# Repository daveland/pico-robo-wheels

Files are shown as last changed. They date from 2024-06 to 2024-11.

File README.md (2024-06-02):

# RoboWheels
This Project will control up to 4 DC servomotors on a robot platform.  The code runs on an RPI pico and uses PWM to perform Speed control of DC motors.  The Pico PIO blocks are used to monitor Quadrature  encoders for motor Speed and position sensing.  Closed loop Velocity control is performed on each motor with Pairs velocity locked to each other for electronic differential mode.  This make the platfor Track straight when 2 motors are determining direction.

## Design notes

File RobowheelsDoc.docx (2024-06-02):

5/2/2024

David Anderson

[company name]

RoboWheels

A Wheel control system for robots

RoboWheels -D.L.Anderson 6/2/24

A universal Wheel control Platform for Robots

Abstract: Robowheels attempts to be a universal control for 2 or 4 wheel DC servo motor robot platforms using microcontrollers. With H-bridge control and Quadrature encoder sensing, the Robowheels software will manage motor speed and position to send the platform in a given direction and speed, with measurable distance. It also supports acceleration control, faults, and wheel slip monitoring. Using Robowheels makes the low level control of the motors much simpler and generic.

When Designing wheeled robot platforms it is often a challenge to integrate the wheel control algorithms into the main system. Many systems are proprietary, and they place tight real-time constraints on the hardware needed to run them. By moving all lower level time critical motor control tasks to a single real-time OS running on a dedicated microcontroller, Robowheels eliminates much of the timing bottlenecks and design discussions. The motor platform is dealt with at a higher level with much fewer and slower timing constraints. Robowheels solves these issue by handling the fiddly details of motor control and gives a clean and deterministic interface for upper software layers to deal with. It still allows fine grained control of motor parameters but with a higher level of abstraction.

Realtime control requires a software system with dedicated processor resuorces organized to provide deterministic control of motor events. In the industry a RTOS software platform is usually used to provide layers of functionality that can meet the timing goals of the control system. The RTOS manages CPU time and events to insure that all tasks are performed at the exact time required by the control algorithm, Delays are managed by a priority system and pool of tasks that address the control algorithm. Interupts are used where appropriate to handle fast events that must be handled immediately. The RTOS and the application work together to meet all the control challengs and get the work done on time.

Key sections are shown below: PWM/Dir control, H-Bridge ,DC servo-Motor, Quadrature encoder, Geartrain and Wheel. The configuration of these objects can be changed to suit the application. Allowing different gear trains or motors to be tested with minimal code re-write.

Wheel

PWM

GearTrain

Quad Encoder

DC Servo motor

H-Bridge

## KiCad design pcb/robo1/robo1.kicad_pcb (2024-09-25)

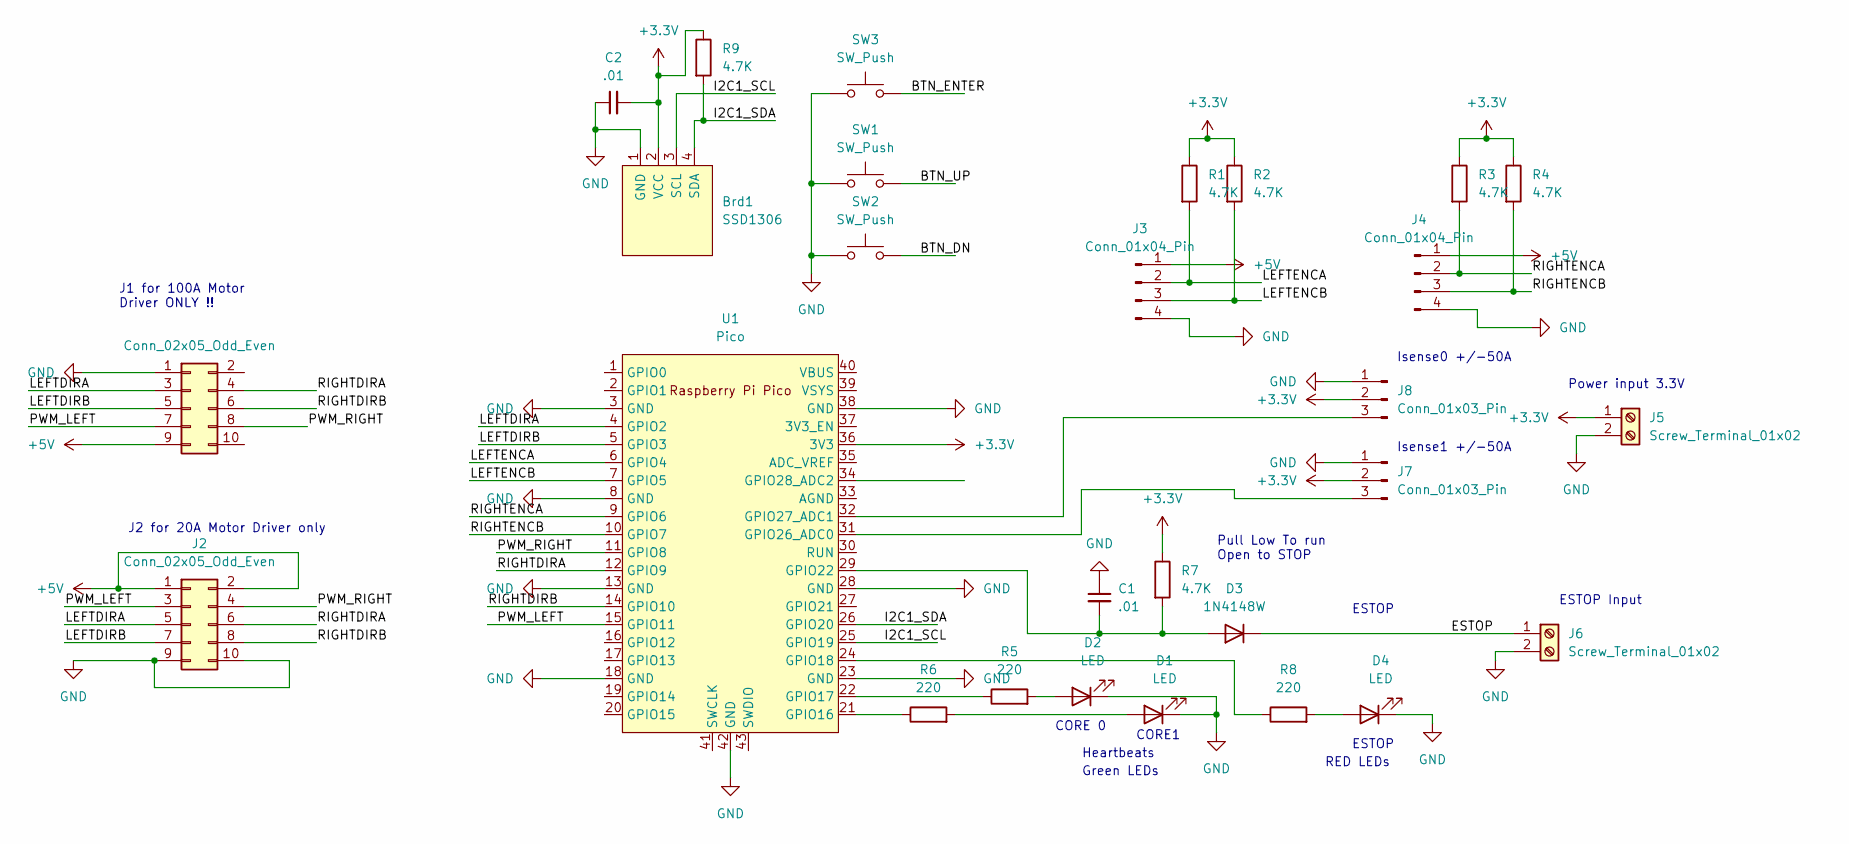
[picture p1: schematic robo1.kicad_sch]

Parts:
Brd1: SSD1306; 128x64OLED
C1, C2: .01; C_0603_1608Metric_Pad1.08x0.95mm_HandSolder
D1, D2, D4: LED; LED_1206_3216Metric_Pad1.42x1.75mm_HandSolder
D3: 1N4148W; D_SOD-123
J1, J2: Conn_02x05_Odd_Even; PinHeader_2x05_P2.54mm_Vertical
J3, J4: Conn_01x04_Pin; PinHeader_1x04_P2.54mm_Vertical
J5, J6: Screw_Terminal_01x02; TerminalBlock_bornier-2_P5.08mm
J7, J8: Conn_01x03_Pin; PinHeader_1x03_P2.54mm_Vertical
R1, R2, R3, R4, R7, R9: 4.7K; R_0201_0603Metric_Pad0.64x0.40mm_HandSolder
R5, R6, R8: 220; R_0201_0603Metric_Pad0.64x0.40mm_HandSolder
SW1, SW2, SW3: SW_Push; SW_PUSH_6mm
U1: Pico; RPi_Pico_SMD_TH

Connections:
+3.3V: Brd1.2 (VCC), C2.2, J5.1, J7.2, J8.2, R1.1, R2.1, R3.1, R4.1, R7.1, R9.1, U1.36 (3V3)
+5V: J1.9, J2.1, J2.2, J3.1, J4.1
/BTN_DN: SW2.2
/BTN_ENTER: SW3.2
/BTN_UP: SW1.2
/ESTOP: D3.1 (K), J6.1
/I2C1_SCL: Brd1.3 (SCL), U1.25 (GPIO19)
/I2C1_SDA: Brd1.4 (SDA), R9.2, U1.26 (GPIO20)
/LEFTDIRA: J1.3, J2.5, U1.4 (GPIO2)
/LEFTDIRB: J1.5, J2.7, U1.5 (GPIO3)
/LEFTENCA: J3.2, R1.2, U1.6 (GPIO4)
/LEFTENCB: J3.3, R2.2, U1.7 (GPIO5)
/PWM_LEFT: J1.7, J2.3, U1.15 (GPIO11)
/PWM_RIGHT: J1.8, J2.4, U1.11 (GPIO8)
/RIGHTDIRA: J1.4, J2.6, U1.12 (GPIO9)
/RIGHTDIRB: J1.6, J2.8, U1.14 (GPIO10)
/RIGHTENCA: J4.2, R3.2, U1.9 (GPIO6)
/RIGHTENCB: J4.3, R4.2, U1.10 (GPIO7)
GND: Brd1.1 (GND), C1.1, C2.1, D1.1 (K), D2.1 (K), D4.1 (K), J1.1, J2.9, J2.10, J3.4, J4.4, J5.2, J6.2, J7.1, J8.1, SW1.1, SW2.1, SW3.1, U1.3 (GND), U1.8 (GND), U1.13 (GND), U1.18 (GND), U1.23 (GND), U1.28 (GND), U1.38 (GND), U1.42 (GND)
unnamed: D1.2 (A), R6.2
unnamed: D2.2 (A), R5.2
unnamed: C1.2, D3.2 (A), R7.2, U1.29 (GPIO22)
unnamed: D4.2 (A), R8.2
unnamed: J7.3, U1.31 (GPIO26_ADC0)
unnamed: J8.3, U1.32 (GPIO27_ADC1)
unnamed: R6.1, U1.21 (GPIO16)
unnamed: R5.1, U1.22 (GPIO17)
unnamed: R8.1, U1.24 (GPIO18)

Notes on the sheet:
ESTOP Input
J2 for 20A Motor Driver only
ESTOP
Isense0 +/-50A
Isense1 +/-50A
Heartbeats
Pull Low To run Open to STOP
Green LEDs
Power input 3.3V
J1 for 100A Motor Driver ONLY !!
CORE1
CORE 0
RED LEDs

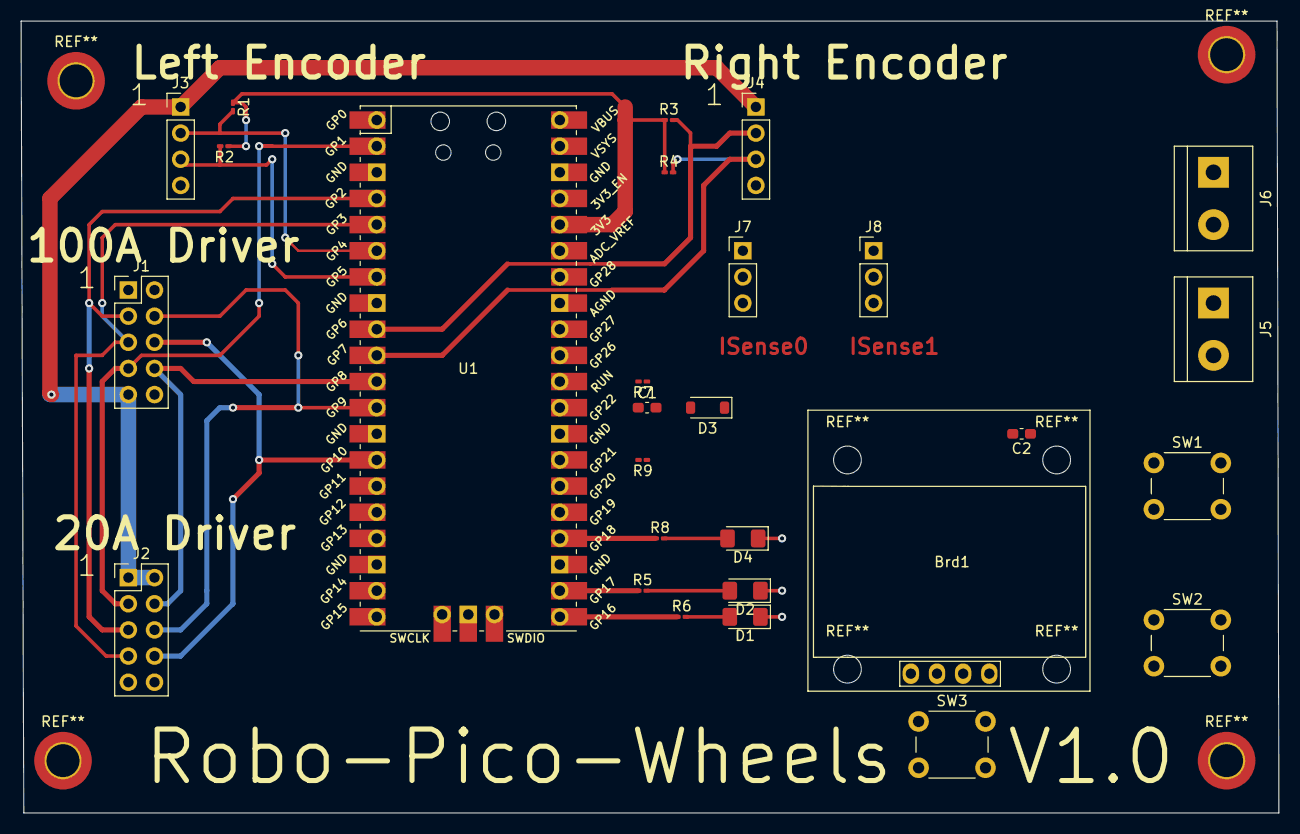
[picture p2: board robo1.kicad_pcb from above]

Board: 2 copper layers, 122.2 x 76.9 mm, 28 parts (0 on the bottom side), 25 nets.

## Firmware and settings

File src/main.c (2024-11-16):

/** pico-robo-wheels july 2024 -- "The beginning of Davenet" and the robot appocolypse
 * Copyright (C) 2024 {David L. Anderson} - All Rights Reserved
 * 
 * This source code is protected under international copyright law.  All rights
 * reserved and protected by the copyright holders.
 * This file is confidential and only available to authorized individuals with the
 * permission of the copyright holders.  If you encounter this file and do not have
 * permission, please contact the copyright holders and delete this file.
 */



#include "FreeRTOS.h"
#include "task.h"
#include "queue.h"
#include <stdio.h>
#include <stdlib.h>
#include "pico/stdlib.h"
#include "pico/unique_id.h"  //eeprom unique_id
#include "string.h"
#include "pico-robo-wheels.pio.h"

// LCD 
#include "ssd1306.h"
//#include "font.h"

//#include "ssd1306.h"
#include "image.h"
#include "acme_5_outlines_font.h"
#include "bubblesstandard_font.h"
#include "crackers_font.h"
#include "BMSPA_font.h"

// Core 0 is managed by Freertos.  


// core 0 starts Core 1 slave running before starting  RTOS Kernel.

// Core 1 is used as a slave and IS NOT managed by FreeRTOS
// Core 1 runs the Quadrature encoders and manages position
// Core 1 runs the PWM for the 2 motors L+R
// Data space is shared by Global Variables ( a bad way i know)
// At this point I don't yet understand how 2 cores Share data without corruption
// due to simultainious access
// do for now Core 1 ( non RT slave)  writes to the Variable space and core 0
// Only reads them..  This works as long as all cor1 handles are inputs

// core 1 handles PIO position interrupts from 2 encoders
// Core 1 handles Velocity calcs from encoders
// core 1 incriments core1 counter every 1 sec 


#include "pico/multicore.h"

#include "hardware/pwm.h" // Hardware PWM
#include "hardware/timer.h" // Timer hardware
#include "hardware/flash.h"
#include "hardware/irq.h"
#include "hardware/pio.h"


//Spinlocks
// Core1 is running data collection routines and modifying shared global varibles
// A single spinlock is used for access to all
// core1 -> Core0 direction data  
// Core1 position L/R updates (encoder interupt based)
// Core1 Velocity L/R updates ( encoder interrupt based)

//core0 -> core1 direction data
// Motor PWM ??  assume motor pwm is defined in Rtos core 0 path planner ??



// Two variables to store core number
volatile int corenum_0  ;
volatile int corenum_1  ;

// Global counter for spinlock experimenting
volatile int global_counter = 0 ;

// Core0-Core1 data spinlock number, initiakized by core0 before core1 startup
int spinlock_num_count ;
spin_lock_t *spinlock_count ;



// Motor controller info
//

enum D100AMtrDir {
    FWD = 1,
    REV = 2,
    BRAKE = 0,
    COAST = 3,
};

//typedef MtrDrverinfo {
  //  uint8_t ctrltype;
  //  uint8_t mtrfwd;
  //  uint8_t mtrrev;
//} Mtr;

//MtrDrverinfo D100A = {.ctrltype=0,.mtrfwd=FWD,.mtrrev=2} ;


#include "pico-robo-wheels.pio.h"
// Core 0 PWM 
// define Motor pwm pins to output pwm and direction for each motor
const uint LeftPwmPin =1;  // GPIO #1
 const uint LeftMtrPinA =2;  // GPIO control of Motor driver Hbridge
 const uint LeftMtrPinB =3;

const uint RightPwmPin =8;  //GPIO #8
 const uint RightMtrPinA =9; // GPIO control of Motor driver Hbridge
 const uint RightMtrPinB =10;

const uint PWMTOP = 15624 ;  //top value for PWM counters 
//Core 1
// define Encoder AB input pins
// Each pair must be adjacent  A+1=B
//Left encoder PIO0 block SM0  and Right encoder PIO1 block SM0
// We load same PIO code into both PIO blocks memory
const int LeftEncA =4; // use 2 pio blocks for now... Should be able to move to one PIO Block
const int LeftEncB =5;  // interrupts are not working like I expect to have 2 "copies" of the same 
const int RightEncA =6; // PIO Program Running on two SM's in the same PIO block and having unique 
const int RightEncB =7; // interrupts to call the count up/down IRQ's 
// seperatly Running on 2 pio blocks solves this for now


//core 1
// Position is 64 bits Signed !!
volatile int64_t LeftPosition ;  // 64 bits
volatile int64_t RightPosition ; //64 bits
volatile uint32_t Core1counter=0; 
volatile uint32_t Core1State;  // state of core1


 //core 1
// motor velocity computed using period of interrupts on each wheel
// meausure time from each interrupt and convert to mS. Then average this
// over several interrupts and cacluate velocity in m/s 
// using tire diameter and gear ratio
//Vel (m/s) =  (1/(Tinterupt*cpr)) / gearRatio * Wheeldiam (M)*PI
volatile int RightVelocity=0;
volatile int LeftVelocity=0;
int cpr=100*4; // encoder pulses per revolution * 4 counts per pulse
int GearRatio = 20;  // ratio from encoder revs to wheel revs
float LeftWheelDiam_m = 0.32385;  // wheel diameter in meters
float RightWheelDiam_m = 0.33385;  // wheel diameter in meters
int comp =0;

//core 1
// we measure encoder distance as a small number. Determined by encoder CPR ( counts per rev)
// and Gear ratio from encoder to wheel , and Wheel Diameter in milimeters.
// Keeping these in different units in integer valibles avoids slow floating point lirary 
// calls ( no floating point unit in Pico RP2040)
// since we have multiple 
int DistEncoderRightuMDec;  // distance in uM per encoder pulse *100 
int DistEncoderLeftuMDec;   // distance in uM per encoder pulse *100 

// core 1 keep the last right and left encoder interrupt times for speed calulation
uint64_t LastRightEncIntTimeuS;  
uint64_t LastLeftEncIntTimeuS; 

//Core 0
uint PIOoffset ;

QueueHandle_t charQueue; // charachters are buffered here

QueueHandle_t cmdQueue; // when char queue forms a command this triggers parsing

pico_unique_board_id_t * FlashIdPtr;  // 8 byte flash id buffer, unique per Pico Flash chip, used fpt liscensing

char * PGMVersion = "0.2.9";

// Floating Point used here ONCE on bootup
void ComputeEncoderDistances() {
    LastRightEncIntTimeuS=0; 
    LastLeftEncIntTimeuS=0;  
// determine the distance in uM  that a wheel moves in one encoder count
// we use this to keep integer math in micrometers 64bit and then multiply by number of us
// to get how far we traveled and compute velocity..

    // (one wheel rotation meters)/GearRatio) = one encoder rotation in meters
    // = /CPR = one encoder Pulse in meters
    // = *1e6 = one encoder pulse in u meters
float DistuMPerCountfloat= ((((RightWheelDiam_m*3.14159)/GearRatio)/cpr) *1000e6 ) ;  // 100 * the distance in uM per encoder pulse
DistEncoderRightuMDec= (int) DistuMPerCountfloat ; //Truncate ?? or round ??

 DistuMPerCountfloat= ((((LeftWheelDiam_m*3.14159)/GearRatio)/cpr) *1000e6 ) ;  // 100 * the distance in uM per encoder pulse
DistEncoderLeftuMDec= (int) DistuMPerCountfloat ; //Truncate ?? or round ??


// figure out how long the division takes in the interrupt encoder handler
//  we need it to be pretty fast .. It should be since there is a 64 Bit 
// Hardware Divider in each core..  
uint64_t BegintimeuS=time_us_64(); //read current 64 bit tic ctr
 uint32_t delta_ticsuS;
for (int i=0;i<1000000;i++) {

    // this takes 1.26us From, here ...
    uint64_t currenttimeuS=(uint32_t)(currenttimeuS-LastRightEncIntTimeuS); // compute delta tics since last encoder interrupr
       LastRightEncIntTimeuS=currenttimeuS;  //save now as new time
       RightVelocity = DistEncoderRightuMDec/delta_ticsuS/1000; // divide by 100 to remove the 100X for significant digits  then convert to um/us = m/s
    ///   to here ...
}
uint64_t donetimeus=time_us_64();

comp=donetimeus-BegintimeuS;


}


// core1 running Bare metal
//------------------------------------------------------------------

static void Left_pio_irq_handler (void) {
   // This distance DistEncoderRight is the  amount of motion in one encoder pulse
    // It depends on the encoder CPR and the GearRatio From  encoder to Wheel position
    // 
       uint64_t currenttimeuS=time_us_64(); //read current 64 bit tic ctr

       uint32_t delta_ticsuS=(uint32_t)(currenttimeuS-LastLeftEncIntTimeuS); // compute delta tics since last encoder interrupr
       LastLeftEncIntTimeuS=currenttimeuS;  //save now as new time
       LeftVelocity = DistEncoderLeftuMDec/delta_ticsuS/1000; // divide by 100 to remove the 100X for significant digits  then convert to um/us = m/s
        // Lock spinlock (without disabling interrupts since we are in the int handler and cannot be interrupted again on core1)
        spin_lock_unsafe_blocking(spinlock_count) ; // get spinlock for core 1(write)-> core 0 (read) global access


         // test Which IRQ was raised by state machine on PIO0 sm1
         // Left encoder is serviced by SM0 With SM flags 
        //printf("leftPosition %d \n",pio0_hw->irq);
        if (pio0_hw->irq & 1) // bit sm0
        { //puts("leftPosition down\n");
            LeftPosition -=1;
        }
        // test if irq 1 was raised
        if (pio0_hw->irq & 2) // bit sm1
        {//puts("leftPosition up\n");
            LeftPosition +=1;
        }
        
        spin_unlock_unsafe(spinlock_count) ;

        // clear both interrupts by setting to 1
        pio0_hw->irq = 3;
}

static void Right_pio_irq_handler (void) {
     // to determine motor speed,  velocity = distance/Time = Meters/second
     //we measure how many 1us tics between Encoder interrupt pulses
     // delta_tics. This is our delta time in us 
     // Then we figure distance traveled in one encoder pulse.
     //  CPR = counts Per rotation.  100 counts in our case
     //  1 count= 360deg/100 = 3.6 degs
     //  500 motor rotations = 1 wheel rotation.
     //  1 wheel rotation = 13 " *PI = 13*3.14159 =40.8401" =1.037 Meters
     // 1.037/gearration=1.037/500= meters per encoder rev =.002074 Meters 
     // meters per encoder pulse = .002074/100 = .00002074 meters
    // each onterrupt call represents one encoder pulse that is a certain number of meters of distance 
    // This distance DistEncoderRight is the  amount of motion in one encoder pulse
    // It depends on the encoder CPR and the GearRatio From  encoder to Wheel position
    // 
       uint64_t currenttimeuS=time_us_64(); //read current 64 bit tic ctr

       uint32_t delta_ticsuS=(uint32_t)(currenttimeuS-LastRightEncIntTimeuS); // compute delta tics since last encoder interrupr
       LastRightEncIntTimeuS=currenttimeuS;  //save now as new time
       RightVelocity = DistEncoderRightuMDec/delta_ticsuS/1000; // divide by 100 to remove the 100X for significant digits  then convert to um/us = m/s
       // 1m/s  = 1e6m/

       // Lock spinlock (without disabling interrupts since we are in the int handler and cannot be interrupted again on core1)
        spin_lock_unsafe_blocking(spinlock_count) ; // get spinlock for core 1(write)-> core 0 (read) global access



// test Which IRQ was raised by state machine on PIO sm1
// this determines if we should count up or down
        if (pio1_hw->irq & 1) //bit sm2
        {//puts("RightPosition up\n");
            RightPosition -=1;
        }
        // test if irq 1 was raised
        if (pio1_hw->irq & 2) //bit sm3
        {//puts("RightPosition up\n");
            RightPosition +=1;
        }

        spin_unlock_unsafe(spinlock_count) ;

        // clear both interrupts by setting to 1
        pio1_hw->irq = 0x3;

}


// setup pio0  to do the left motor encoder
void SetupPioEncoderLeft( )  {
    LeftPosition=0;
    LeftVelocity=0;
    LastLeftEncIntTimeuS=time_us_64();
    
   // pio 0 SM0 is used to track A nd B left pulses
        PIO pio = pio0;
        // state machine 0
        uint8_t sm = 0;
        // configure the used pins as input with pull up
        pio_gpio_init(pio, LeftEncA);
        gpio_set_pulls(LeftEncA, true, false);
        pio_gpio_init(pio, LeftEncB);
        gpio_set_pulls(LeftEncB, true, false);
        // load the pio program into the pio memory
         PIOoffset = pio_add_program(pio, &pico_robo_wheels_program);
        // make a sm config
        pio_sm_config c = pico_robo_wheels_program_get_default_config(PIOoffset);
        // set the 'in' pins
        sm_config_set_in_pins(&c, LeftEncA);
        // set shift to left: bits shifted by 'in' enter at the least
        // significant bit (LSB), no autopush
        sm_config_set_in_shift(&c, false, false, 0);
        // set the IRQ handler
        irq_set_exclusive_handler(PIO0_IRQ_0, Left_pio_irq_handler);
        // enable the IRQ
        irq_set_enabled(PIO0_IRQ_0, true);
        // SM0 and SM2 are connected to up/down interrupt for Left Motor
        // on SM0 triggering Core1 IRQ0 with SMbits 0 and 2
        pio0_hw->inte0 = PIO_IRQ0_INTE_SM0_BITS | PIO_IRQ0_INTE_SM1_BITS;
        // init the sm.
        // Note: the program starts after the jump table -> initial_pc = 16
        pio_sm_init(pio, sm, 16, &c);
        // enable the sm
        pio_sm_set_enabled(pio, sm, true);
    }


// setup pio0  to do the Right motor encoder
void SetupPioEncoderRight( )  {
    RightPosition=0;
    RightVelocity=0;
    LastRightEncIntTimeuS=time_us_64();

   // pio 0 is used
        PIO pio = pio1;
        // state machine 1
        uint8_t sm = 0;
        // configure the used pins as input with pull up
       
        pio_gpio_init(pio, RightEncA);
        gpio_set_pulls(RightEncA, true, false);
        pio_gpio_init(pio, RightEncB);
        gpio_set_pulls(RightEncB, true, false);
        
        // load the pio program into the pio memory
        uint offset = pio_add_program(pio, &pico_robo_wheels_program);
        // make a sm config
        
        pio_sm_config c = pico_robo_wheels_program_get_default_config(offset);
        // set the 'in' pins
       
        sm_config_set_in_pins(&c, RightEncA);
        // set shift to left: bits shifted by 'in' enter at the least
        // significant bit (LSB), no autopush
        sm_config_set_in_shift(&c, false, false, 0);
          
        // set the IRQ handler
        irq_set_exclusive_handler(PIO1_IRQ_0, Right_pio_irq_handler);
        // enable the IRQ
        irq_set_enabled(PIO1_IRQ_0, true);
        // SM1 and SM3 are connected to up/down interrupt for Right Motor
        // on SM1 triggering Core1 IRQ1 with SMbits 1 and 3
        pio1_hw->inte0 = PIO_IRQ0_INTE_SM0_BITS | PIO_IRQ0_INTE_SM1_BITS;
        // init the sm.
        // Note: the program starts after the jump table -> initial_pc = 16
        pio_sm_init(pio, sm, 16, &c);
        // enable the sm
        pio_sm_set_enabled(pio, sm, true);
        
    }


void InitMotorABPins() {
//gpio_set_dir(LeftPwmPin,true);
//gpio_set_drive_strength(LeftPwmPin,GPIO_DRIVE_STRENGTH_12MA);
//gpio_set_drive_strength(LeftMtrPinA,GPIO_DRIVE_STRENGTH_12MA);
//gpio_set_drive_strength(LeftMtrPinB,GPIO_DRIVE_STRENGTH_12MA);

gpio_init(LeftMtrPinA);
gpio_init(LeftMtrPinB);

gpio_init(RightMtrPinA);
gpio_init(RightMtrPinB);

gpio_set_dir(LeftMtrPinA,GPIO_OUT);
gpio_set_dir(LeftMtrPinB,GPIO_OUT);

  gpio_put(LeftMtrPinA,1);
  gpio_put(LeftMtrPinB,1);
//gpio_set_dir(RightPwmPin,true);
gpio_set_dir(RightMtrPinA,GPIO_OUT);
gpio_set_dir(RightMtrPinB,GPIO_OUT);

  gpio_put(RightMtrPinA,1);
  gpio_put(RightMtrPinB,1);
    
}

void InitMotorPWMPins () {

 puts("Setup pwm\n");
     // Tell GPIO s it is allocated to the PWM
    gpio_set_function(RightPwmPin, GPIO_FUNC_PWM);
    gpio_set_function(LeftPwmPin, GPIO_FUNC_PWM);

    // Find out which PWM slice is connected to pwm GPIO then configure Pwm
    // Fpwm= Fsys/period  = 125Mhz/ 15624  = 8000.6 hz
    // period =15624 = (Top +1) * (Phase corr+1) *( Divint + DivFrac/16)
    //
    uint Rightslice_num = pwm_gpio_to_slice_num(RightPwmPin);
    pwm_set_clkdiv_int_frac(Rightslice_num,1,0);  // Divint, divfrac  for 8Khz PWM rate
    uint Leftslice_num = pwm_gpio_to_slice_num(LeftPwmPin);
    pwm_set_clkdiv_int_frac(Leftslice_num,1,0);
    // set Top value 8Khz ???
        pwm_set_wrap(Rightslice_num, PWMTOP); // 
          pwm_set_wrap(Leftslice_num, PWMTOP); // 
    // Set channel A B to 50% duty cycle
    pwm_set_chan_level(Rightslice_num, PWM_CHAN_A, PWMTOP/2 ); //50% duty cycle
    pwm_set_chan_level(Leftslice_num, PWM_CHAN_B, PWMTOP/2); //50% duty cycle
    //pwm_set_phase_correct(Rightslice_num,true);
    //pwm_set_phase_correct(Leftslice_num,true);

    // Set the PWM running
    pwm_set_enabled(Rightslice_num, true);
    puts("pwm Right enabled\n");

    pwm_set_enabled(Leftslice_num, true);
    puts("pwm Left enabled\n");
}



// core 1 code here --- not managed by RTOS !!!
void core1_entry(void) {
 
corenum_1=get_core_num();

//toggle GPIO #1 to show core 0 is running
// run core 1 for
// PWM Generators for Motor control
// direction stop start control
// keep position of each wheel
// using Quadrature Encoders for motor position ( PIO inpput buffers and counting code)
// Velocty calulation for each motor
// virtual transmission locking Left and right speeds together
// Acceleration/decelleration control
Core1State =98;

ComputeEncoderDistances();
SetupPioEncoderLeft();
SetupPioEncoderRight();

Core1State =1;

pico_get_unique_board_id(FlashIdPtr); // used as sofware key

// setup PWM Pin I/O
InitMotorABPins();
InitMotorPWMPins();


Core1State =3;
printf("Core 1 Started\n");
while (1) {
// set pwm I/O to defult
// Pwm =0%  stopped dir =FWD

// no interrupts arused for cpu ctr,, just a sleep loop so no need to disable interrupts
// Lock spinlock (without disabling interrupts since we are in the int handler and cannot be interrupted again on core1)
spin_lock_unsafe_blocking(spinlock_count) ; // get spinlock for core 1(write)-> core 0 (read) global access
Core1counter+=1; // foreground action,  interrupts do not touch Core1counter, but core0 reads it
// this should be safe with AB lite bus stalls handling contention with only 1 writer and 1 reader 
spin_unlock_unsafe(spinlock_count) ;

sleep_ms(1000);
//printf("Core 1 Running %d\n",Core1counter);
// Start Encoder PIO and sampling of  position
// set PosL and PosR to 0

// wait for Motor enable 

}
}

// Safe access to core1 counter
uint32_t get_Core1Counter() {
spin_lock_unsafe_blocking(spinlock_count) ; // get spinlock for core 1(write)-> core 0 (read) global access
uint32_t tmp= Core1counter;
// this should be safe with AB lite bus stalls handling contention with only 1 writer and 1 reader 
spin_unlock_unsafe(spinlock_count) ;
 return(tmp);
}

// Safe access to LeftPosition 
uint32_t get_LeftPosition() {
spin_lock_unsafe_blocking(spinlock_count) ; // get spinlock for core 1(write)-> core 0 (read) global access
int64_t tmp= LeftPosition;
// this should be safe with AB lite bus stalls handling contention with only 1 writer and 1 reader 
spin_unlock_unsafe(spinlock_count) ;
 return(tmp);
}

// Safe access to LeftPosition 
uint32_t get_RightPosition() {
spin_lock_unsafe_blocking(spinlock_count) ; // get spinlock for core 1(write)-> core 0 (read) global access
int64_t tmp= RightPosition;
// this should be safe with AB lite bus stalls handling contention with only 1 writer and 1 reader 
spin_unlock_unsafe(spinlock_count) ;
 return(tmp);
}





//Core 0 --- Running under Free RTOS 
//-----------------------------------------------------------
void led_task()
{   int i=0;
    const uint LED_PIN = PICO_DEFAULT_LED_PIN;
    gpio_init(LED_PIN);
    
    gpio_set_dir(LED_PIN, GPIO_OUT);
  
 
    while (true) {
        gpio_put(LED_PIN, 1);
    
        vTaskDelay(500);
        gpio_put(LED_PIN, 0);
      
        vTaskDelay(500);
        //puts("Robowheels V0.1 \n");
       //printf("count %d\n",i++);
    }
}

// Get usbserial input and put it on the input Queue 
void USBSerial_Inputtask()
{   
   //gets(inputbuffer ); // this blocks until a CR is entered'

// push all received chars from usb input to the charqQueue 
//  when charqueue has a cr then we process command in command parsere which empties the queue
int chint;
char ch;
    while (true) {
        // change this later to interrupt based, for now we poll  ....
        chint= getchar_timeout_us(0);

        if (chint != PICO_ERROR_TIMEOUT) {
            ch=(char)chint;
            //printf("A-CH usbread %d \n",ch);
            int pflag=pdFALSE;
            while(!pflag){
            //printf("A-CH Charque add %d \n",ch);
              pflag=  xQueueSendToBack(charQueue,& ch,0); // if fails retry char 
             //printf("A-CharQueue length %d \n", uxQueueMessagesWaiting(charQueue));

                 vTaskDelay(1); //delay 1ms
            }
             pflag=pdFALSE;

            //printf("USBchar val %d Sent\n",(int) ch);
            if (ch==0xd)  {
                // printf("A- add cmdqueue %d \n",ch);
              pflag = xQueueSendToBack(cmdQueue,& ch,0); // if it fails retry.
             // printf("A- pflag %d \n", pflag);
             //  printf("A-cmdQueue length %d \n", uxQueueMessagesWaiting(cmdQueue));
                vTaskDelay(1); //delay 1ms
             //  printf("A-cmdQueue length %d \n", uxQueueMessagesWaiting(cmdQueue));
             //  printf("A-CharQueue length %d \n", uxQueueMessagesWaiting(charQueue));
            }


        } 
       vTaskDelay(10); //delay 1ms 

    }
}

int cmdPosa () {

}
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
int main()
{
    stdio_init_all();
// create queue to hold 128 chars

OLED_setup_gpios();
//OLED_animation();

corenum_0=get_core_num();

 // Claim and initialize a spinlock for core 0 
    spinlock_num_count = spin_lock_claim_unused(true) ;
    spinlock_count = spin_lock_init(spinlock_num_count) ;



 multicore_launch_core1(core1_entry);


charQueue = xQueueCreate( 128, sizeof( char ) ); //128 char buffer
cmdQueue = xQueueCreate( 100, sizeof( char ) ); //10 cmd avalible  buffer, one CR addred to this per cmd line in input buffer, signals parser
    xTaskCreate(led_task, "LED_Task", 256, NULL, 1, NULL);
    xTaskCreate(USBSerial_Inputtask, "USBSerial_Inputtask", 256, NULL, 3, NULL);
    xTaskCreate(InputCmd_task, "InputCmd_task", 256, NULL, 2, NULL);
    xTaskCreate(OLED_animation_Task, "OLED_Task", 256, NULL, 1, NULL);
    vTaskStartScheduler();
    puts("Start scheduler\n");
    puts("Robowheels V0.1 \n");

    while(1){};
}

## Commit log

2024-06-02 Added docs
    XLS for model and Doc for overview and API
    [Robowheels.xls.xlsx]
2024-06-24 added DOCs removed printf debug
    [Block diagram.xlsx, Robowheels.xls.xlsx]
2024-07-06 update Core1 and PIO
    Pio for encoder services 2 SM machines, updated xls docs
    [Block diagram.xlsx]
2024-07-06 Core 1 running , pwm uncheacked
    Core1 booted and counting. encoder interrupts enabled, need to check them
2024-07-08 Put right encoder on PIO1
    Using both PIO's for encoders
    might be able to recode for one PIO Block
2024-07-19 add speed calcs to core 1
    [Block diagram.xlsx]
2024-07-27 Update Velocity calcs
    [Block diagram.xlsx]
2024-07-27 updated board id
2024-07-27 V0.2.2 Pushed pins for MTR A/B
    Moved Pins on Encoder and motor to remove DIR signal and change to MTRA and MTR B signal
    [Block diagram.xlsx]
2024-07-29 added cmds, mtr dir
    added FW,RT,LT,ST,TV, and PW cmds
    [Block diagram.xlsx]
2024-08-04 PW command in Decimal pct
    PW,35 sets both PWM chan values to 35%
    1% resolution
2024-09-03 add kicad pcb
    Kicad pcb added
    [Block diagram.xlsx, robo1.kicad_pcb, robo1.kicad_sch]
2024-09-03 add kicad git ignore
2024-09-03 pcb outline
    added mounting holes and text labels
    [robo1.kicad_pcb]
2024-09-24 Add OLED to PCB
    OLED added to pcb
    [robo1.kicad_pcb, robo1.kicad_sch]
2024-09-25 PCB added Isense connectors
    [robo1.kicad_pcb, robo1.kicad_sch]
2024-10-02 add oled
    [robo1.kicad_sch]
2024-11-05 add rpi pico flavor free rtos
2024-11-05 Runs on RP2350 --
    Must run Board configure and answer no !!!!
